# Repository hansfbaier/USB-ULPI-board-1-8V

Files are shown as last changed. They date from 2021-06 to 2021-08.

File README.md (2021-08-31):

USB ULPI high speed PHY with 1.8V IO voltage
and Waveshare USB3300 board pinout
===

[][cc-by-sa]

This work is licensed under a [Creative Commons Attribution-NonCommercial-ShareAlike 4.0 International License][cc-by-sa].

[][cc-by-sa]

[cc-by-sa]: http://creativecommons.org/licenses/by-nc-sa/4.0/
[cc-by-sa-image]: https://licensebuttons.net/l/by-nc-sa/4.0/88x31.png
[cc-by-sa-shield]: https://img.shields.io/badge/License-CC%20BY--NC--SA%204.0-lightgrey.svg

## Images

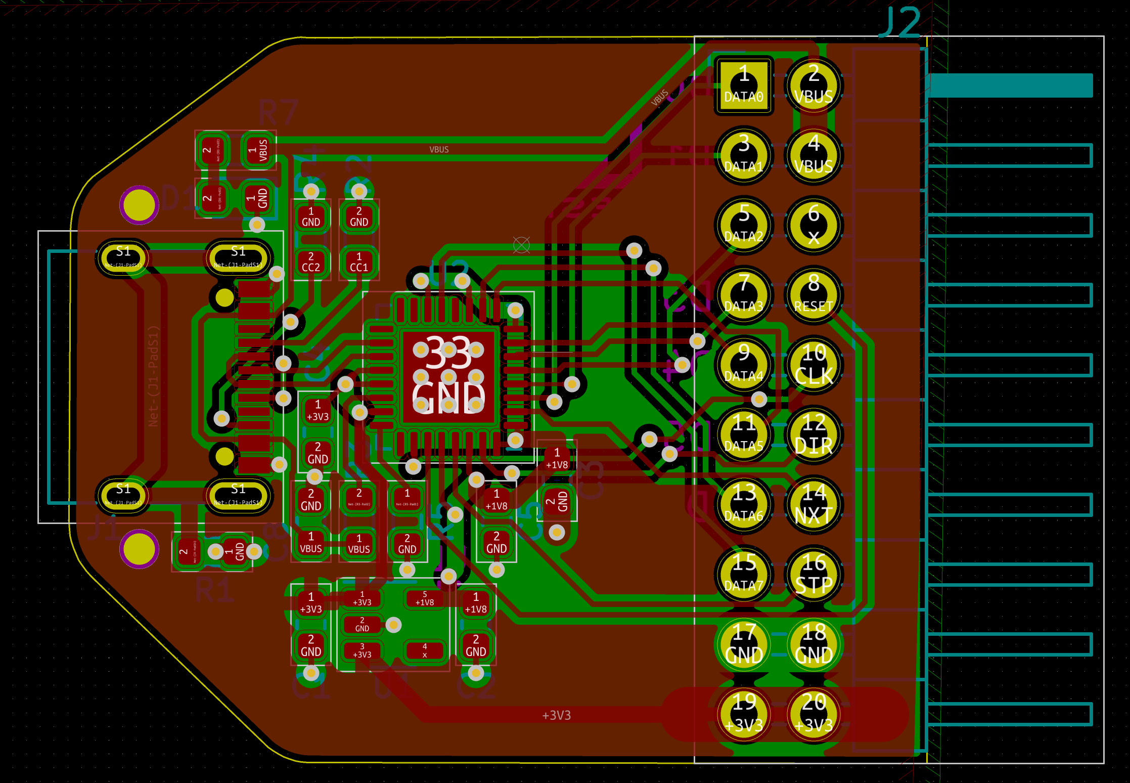
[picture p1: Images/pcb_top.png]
PCB design

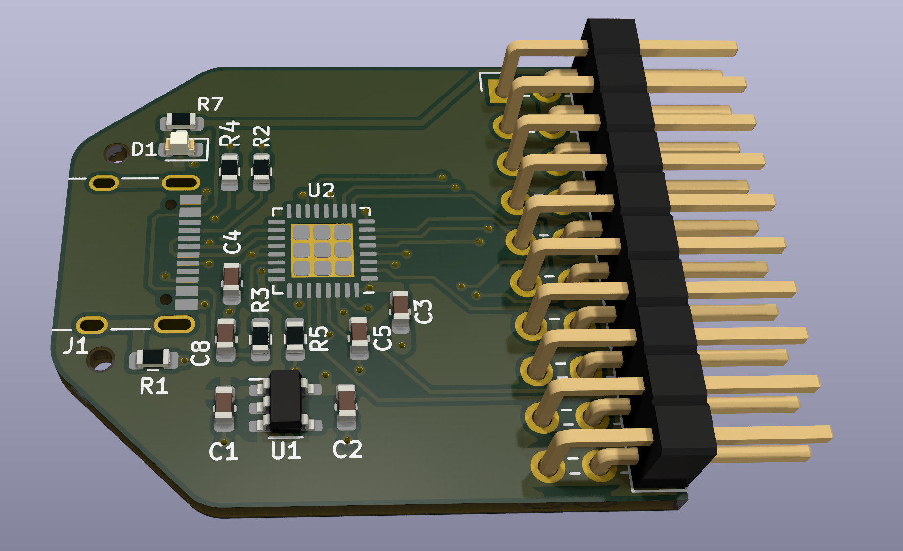
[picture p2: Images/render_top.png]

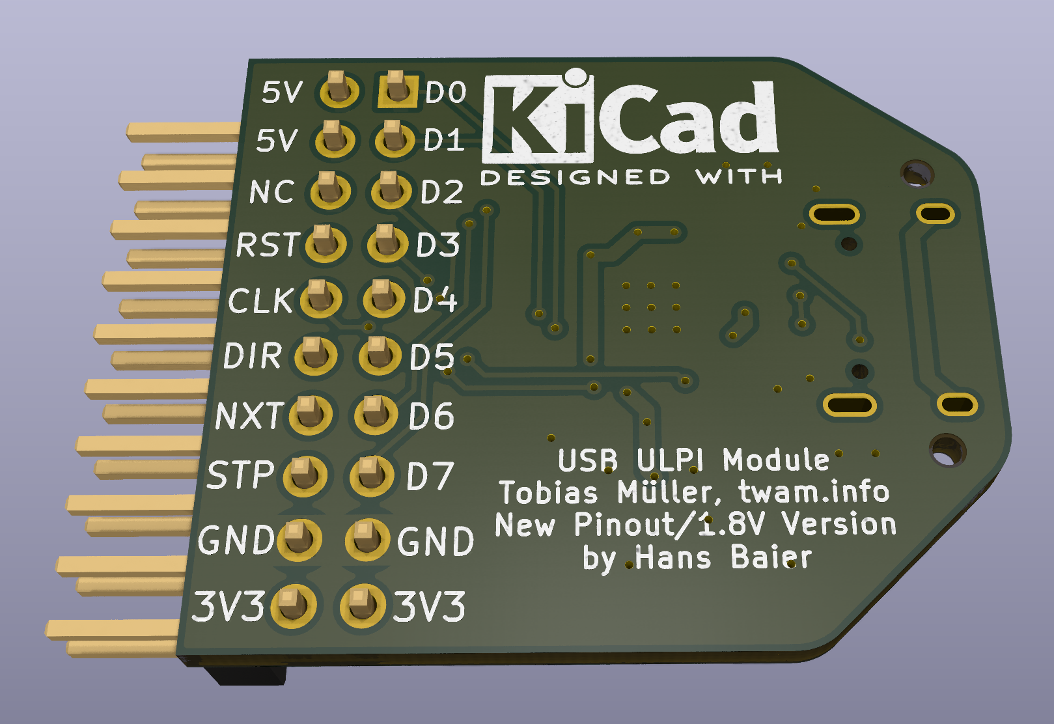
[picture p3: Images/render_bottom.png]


### JLCPCB

PCBs can be ordered fully-assembled (besides the pin header) from [JLCPCB](https://jlcpcb.com). Required files are
[PmodUsbUlpi_cpl_jlc.csv](PmodUsbUlpi_cpl_jlc.csv), [PmodUsbUlpi_bom_jlc.csv](PmodUsbUlpi_cpl_jlc.csv) and
[Gerber/PmodUsbUlpi.zip](Gerber/UsbUlpi.zip).

## Status
I am not sure the board works yet. I could not get it working on a couple of boards.
The 3.3V Version it is also very board dependent, on some boards it would work,
on others not, but I didn't test as many yet as with the 3.3V version.

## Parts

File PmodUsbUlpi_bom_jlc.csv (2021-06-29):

Comment | Designator | Footprint | LCSC
1u | C1 | Capacitor_SMD:C_0603_1608Metric | C15849
10u | C2 | Capacitor_SMD:C_0603_1608Metric | C19702
100n | C3,C5 | Capacitor_SMD:C_0603_1608Metric | C14663
2u2 | C4,C8 | Capacitor_SMD:C_0603_1608Metric | C23630
green | D1 | LED_SMD:LED_0603_1608Metric | C72043
USB_C_Receptacle_USB2.0 | J1 | Connector_USB:USB_C_Receptacle_XKB_U262-16XN-4BVC11 | C165948
2x10 Header | J2 | Connector_PinHeader_2.54mm:PinHeader_2x10_P2.54mm_Horizontal
1M | R1 | Resistor_SMD:R_0603_1608Metric | C22935
5k1 | R2,R4 | Resistor_SMD:R_0603_1608Metric | C23186
10k | R3 | Resistor_SMD:R_0603_1608Metric | C25804
8k06 1% | R5 | Resistor_SMD:R_0603_1608Metric | C23112
15k | R7 | Resistor_SMD:R_0603_1608Metric | C22809
TPS76318 | U1 | Package_TO_SOT_SMD:SOT-23-5 | C7099
USB3320 | U2 | Package_DFN_QFN:QFN-32-1EP_5x5mm_P0.5mm_EP3.3x3.3mm | C132156

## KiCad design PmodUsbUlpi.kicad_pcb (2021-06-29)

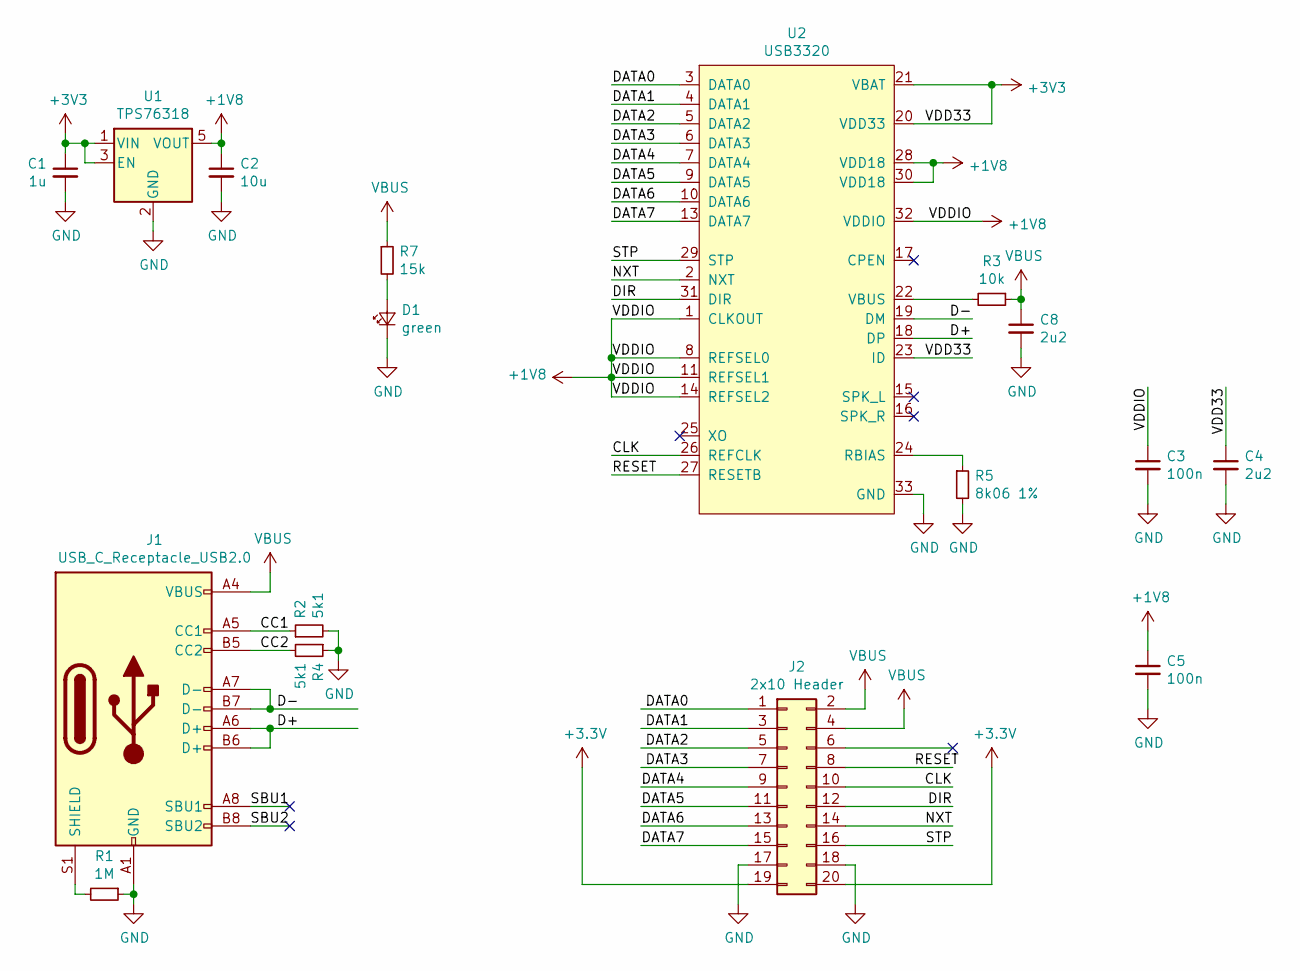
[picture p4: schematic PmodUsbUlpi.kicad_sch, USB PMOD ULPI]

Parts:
C1: 1u; C_0603_1608Metric; LCSC C15849
C2: 10u; C_0603_1608Metric; LCSC C19702
C3, C5: 100n; C_0603_1608Metric; LCSC C14663
C4, C8: 2u2; C_0603_1608Metric; LCSC C23630
D1: green; LED_0603_1608Metric; LCSC C72043
J1: USB_C_Receptacle_USB2.0; USB_C_Receptacle_XKB_U262-16XN-4BVC11; LCSC C165948
J2: 2x10 Header; PinHeader_2x10_P2.54mm_Horizontal
R1: 1M; R_0603_1608Metric; LCSC C22935
R2, R4: 5k1; R_0603_1608Metric; LCSC C23186
R3: 10k; R_0603_1608Metric; LCSC C25804
R5: 8k06 1%; R_0603_1608Metric; LCSC C23112
R7: 15k; R_0603_1608Metric; LCSC C22809
U1: TPS76318; SOT-23-5; LCSC C7099
U2: USB3320; QFN-32-1EP_5x5mm_P0.5mm_EP3.3x3.3mm; LCSC C132156

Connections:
+1V8: C2.1, C3.1, C5.1, U1.5 (VOUT), U2.1 (CLKOUT), U2.8 (REFSEL0), U2.11 (REFSEL1), U2.14 (REFSEL2), U2.28 (VDD18), U2.30 (VDD18), U2.32 (VDDIO)
/CC1: J1.A5 (CC1), R2.1
/CC2: J1.B5 (CC2), R4.2
/CLK: J2.10, U2.26 (REFCLK)
/D+: J1.A6 (D+), J1.B6 (D+), U2.18 (DP)
/D-: J1.A7 (D-), J1.B7 (D-), U2.19 (DM)
/DATA0: J2.1, U2.3 (DATA0)
/DATA1: J2.3, U2.4 (DATA1)
/DATA2: J2.5, U2.5 (DATA2)
/DATA3: J2.7, U2.6 (DATA3)
/DATA4: J2.9, U2.7 (DATA4)
/DATA5: J2.11, U2.9 (DATA5)
/DATA6: J2.13, U2.10 (DATA6)
/DATA7: J2.15, U2.13 (DATA7)
/DIR: J2.12, U2.31 (DIR)
/NXT: J2.14, U2.2 (NXT)
/RESET: J2.8, U2.27 (RESETB)
/SBU1: J1.A8 (SBU1)
/SBU2: J1.B8 (SBU2)
/STP: J2.16, U2.29 (STP)
GND: C1.2, C2.2, C3.2, C4.2, C5.2, C8.2, D1.1 (K), J1.A1 (GND), J1.A12 (GND), J1.B1 (GND), J1.B12 (GND), J2.17, J2.18, R1.1, R2.2, R4.1, R5.2, U1.2 (GND), U2.33 (GND)
unnamed: D1.2 (A), R7.2
unnamed: J1.S1 (SHIELD), R1.2
unnamed: R3.2, U2.22 (VBUS)
unnamed: R5.1, U2.24 (RBIAS)
VBUS: C8.1, J1.A4 (VBUS), J1.A9 (VBUS), J1.B4 (VBUS), J1.B9 (VBUS), J2.2, J2.4, R3.1, R7.1

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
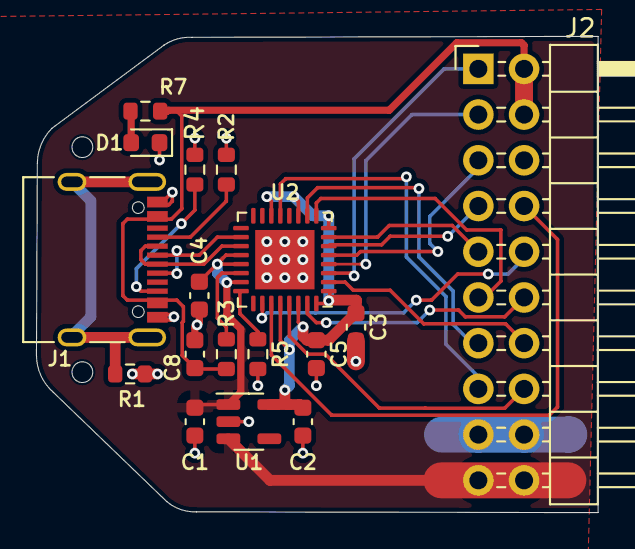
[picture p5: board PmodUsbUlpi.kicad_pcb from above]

Board: 2 copper layers, 31.2 x 26.5 mm, 18 parts (1 on the bottom side), 25 nets.

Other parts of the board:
REFm**: KiCad-Logo2_5mm_SilkScreen

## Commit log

2021-06-29 First Version with Waveshare Pinout
    [PmodUsbUlpi-B_Cu.gbl, PmodUsbUlpi-B_Cu.gbr, PmodUsbUlpi-B_Mask.gbr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]
2021-06-29 first version with 1.8V
    [PmodUsbUlpi.kicad_pcb, PmodUsbUlpi.kicad_sch]
2021-06-29 Tweak a couple of traces (better crossings)
    [PmodUsbUlpi.kicad_pcb]
2021-06-29 fix PCB image version
2021-06-29 update production files
    [PmodUsbUlpi-B_Cu.gbl, PmodUsbUlpi-B_Mask.gbs, PmodUsbUlpi-B_Paste.gbp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]
2021-06-29 Update Gerber ZIP file and README

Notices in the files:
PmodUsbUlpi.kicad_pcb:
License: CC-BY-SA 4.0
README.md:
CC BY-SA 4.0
